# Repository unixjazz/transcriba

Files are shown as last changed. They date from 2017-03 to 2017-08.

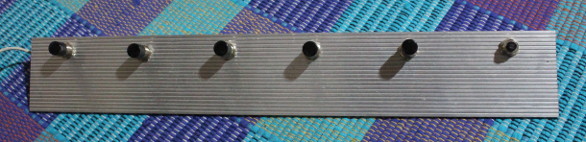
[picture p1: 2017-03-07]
img/pedal_0.1.jpg

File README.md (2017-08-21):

# Transcriba 0.3

Integrates VLC media player with an arduino-based USB pedal for audio
transcription.
 
This script is based on Jeffrey Ness' [raw keyboad access
code](https://github.com/jness).  It was inspired and re-written from
'vlccontrol' by [Derek
Barnett](https://wiki.videolan.org/How_to_use_VLC_for_transcription_in_linux).
It uses Al's [Pyperclip](https://pypi.python.org/pypi/pyperclip/1.5.1) for the
usage of the clipboard function on Mac, Windoze, and Linux.
 
Tested with the PRO MICRO Leonardo-compatible board. Here is the pinout: (it 
works with other Leonardo-compatible boards, Teensy, etc.)

```
Pin     Key Assignment            Function
------------------------------------------------
D02     KEY_LEFTCTRL + KEY_F7     Pause/Play 
D03     KEY_LEFTCTRL + KEY_F8     Get Timecode
D04     KEY_LEFTCTRL + KEY_F9     Jump Forward 
D05     KEY_LEFTCTRL + KEY_F10    Jump Backward
D06     KEY_LEFTCTRL + KEY_F11    Speed-Up  
D07     KEY_LEFTCTRL + KEY_F12    Slow-Down
```

## Getting Started

You need to configure VLC before using the script:

* Open VLC: preferences: advanced preferences and configure its interface to 
use 'RC', check the option 'fake tty' and 'UNIX socket command input' to 
the path of the script;
 
* Open 'keyboard.map' for a list of keycodes. Edit transcriba.py and change the
keycodes according to your environment;

* Plug your USB pedal and launch the script.

## Assembly Instructions

The prototype was based on a L-shaped aluminum bar (which can be found in any
hardware store), a collection of buttons, wires, and an ATmega32U4 MCU (which
can be found in many projects, most notably on the Arduino Leonardo):

[Pedal Transcriba prototype](pedal_0.1.jpg)

TODO: describe the assembly process w/ the PCB, as soon as it is ready!

## Licensing

Each dependency has specific licensing requirements. Check their respective
files for further information.  This script is distributed under the GPL
version 2. For further information, read 'LICENSE'.

*Enjoy Transcribing!*
 (just kidding...)

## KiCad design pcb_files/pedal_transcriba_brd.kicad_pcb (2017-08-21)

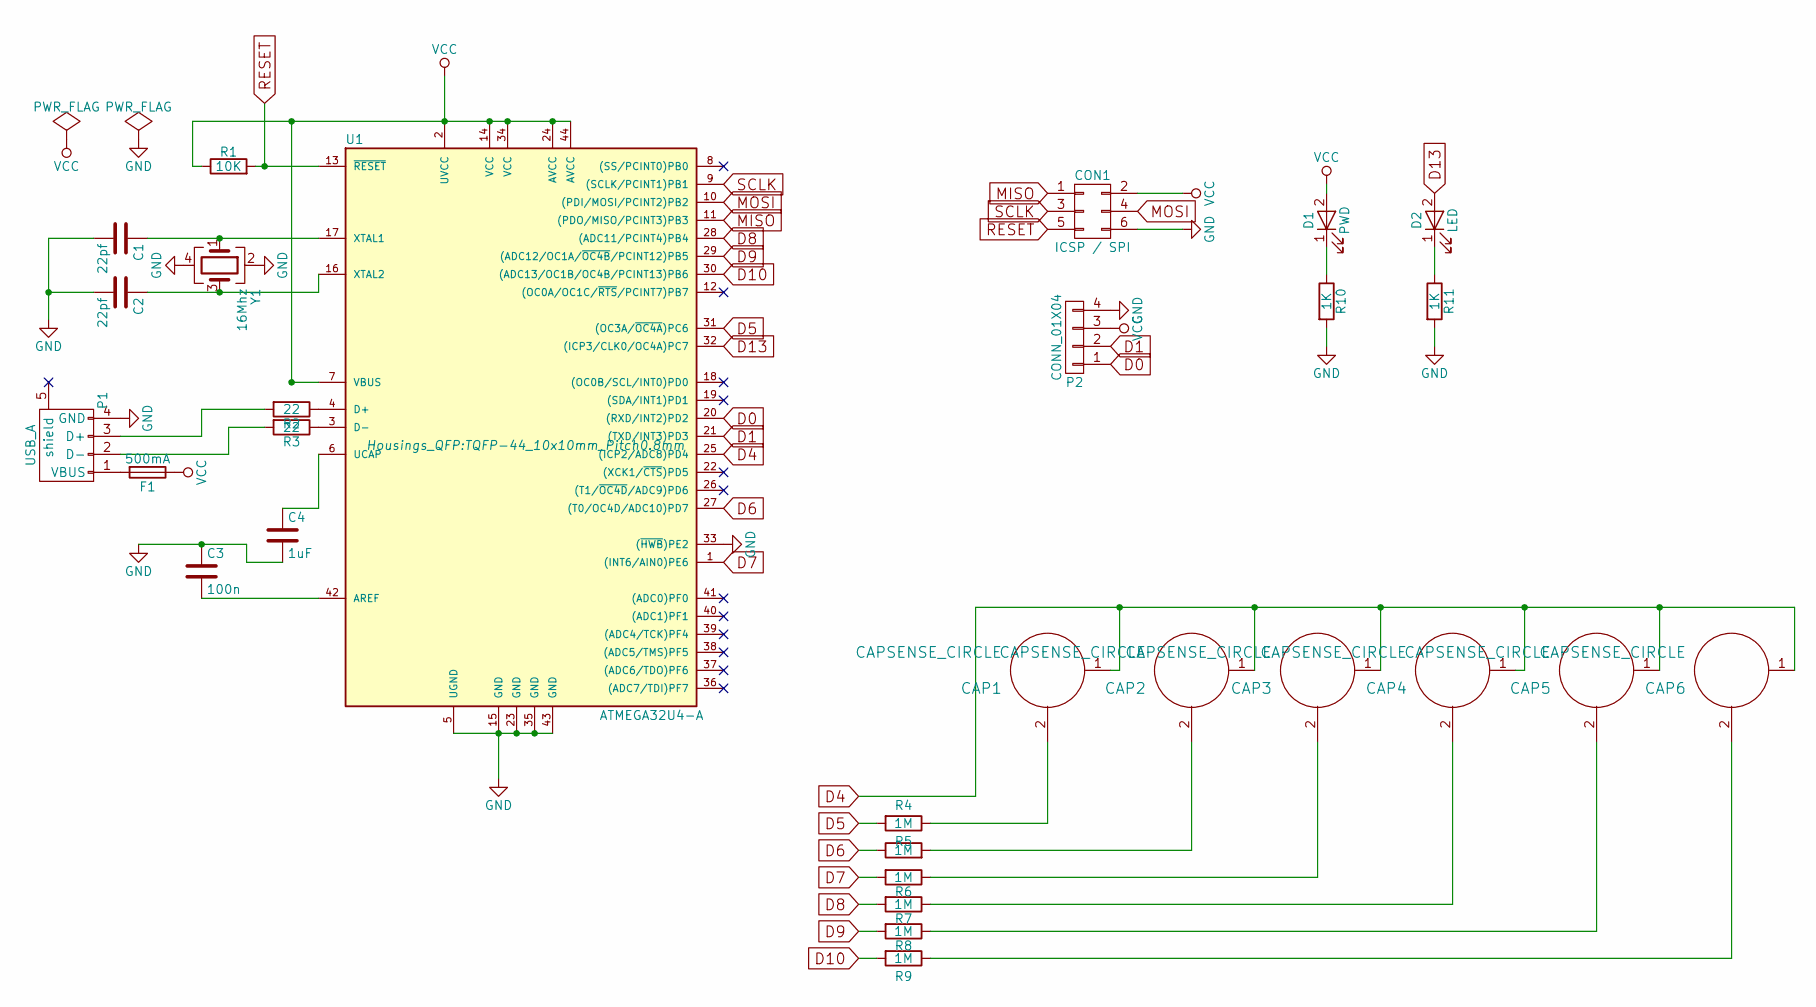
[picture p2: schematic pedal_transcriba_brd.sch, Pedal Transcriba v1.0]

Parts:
C1, C2: 22pf; C_0201
C3: 100n; C_0201
C4: 1uF; C_0201
CAP1, CAP2, CAP3, CAP4, CAP5, CAP6: CAPSENSE_CIRCLE; CAPSENSE-CIRCLE-D10MM-MOD
CON1: ICSP / SPI; Pin_Header_Straight_2x03
D1: PWD; LED_0603
D2: LED; LED_0603
F1: 500mA; Fuse_SMD1206_Reflow
P1: USB_A; USB_Micro-B_10103594-0001LF
P2: CONN_01X04; Pin_Header_Straight_1x04
R1: 10K; R_0201
R2, R3: 22; R_0201
R4, R5, R6, R7, R8, R9: 1M; R_0201
R10, R11: 1K; R_0201
U1: ATMEGA32U4-A; TQFP-44_10x10mm_Pitch0.8mm
Y1: 16Mhz; Crystal_SMD_Abracon_ABM3B-4pin_5.0x3.2mm

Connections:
D0: P2.1, U1.20 ((RXD/INT2)PD2)
D1: P2.2, U1.21 ((TXD/INT3)PD3)
D4: CAP1.1 (BUTTON), CAP2.1 (BUTTON), CAP3.1 (BUTTON), CAP4.1 (BUTTON), CAP5.1 (BUTTON), CAP6.1 (BUTTON), U1.25 ((ICP2/ADC8)PD4)
D5: R4.2, U1.31 ((OC3A/~OC4A~)PC6)
D6: R5.1, U1.27 ((T0/OC4D/ADC10)PD7)
D7: R6.2, U1.1 ((INT6/AIN0)PE6)
D8: R7.2, U1.28 ((ADC11/PCINT4)PB4)
D9: R8.2, U1.29 ((ADC12/OC1A/~OC4B~/PCINT12)PB5)
D10: R9.2, U1.30 ((ADC13/OC1B/OC4B/PCINT13)PB6)
D13: D2.2 (A), U1.32 ((ICP3/CLK0/OC4A)PC7)
GND: C1.2, C2.2, C3.1, C4.2, CON1.6, P1.4 (GND), P2.4, R10.2, R11.2, U1.5 (UGND), U1.15 (GND), U1.23 (GND), U1.33 ((~HWB~)PE2), U1.35 (GND), U1.43 (GND), Y1.2, Y1.4
MISO: CON1.1, U1.11 ((PDO/MISO/PCINT3)PB3)
MOSI: CON1.4, U1.10 ((PDI/MOSI/PCINT2)PB2)
unnamed: C1.1, U1.17 (XTAL1), Y1.1
unnamed: C2.1, U1.16 (XTAL2), Y1.3
unnamed: C3.2, U1.42 (AREF)
unnamed: C4.1, U1.6 (UCAP)
unnamed: CAP1.2, R4.1
unnamed: CAP2.2, R5.2
unnamed: CAP3.2, R6.1
unnamed: CAP4.2, R7.1
unnamed: CAP5.2, R8.1
unnamed: CAP6.2, R9.1
unnamed 23: D1.1 (K), R10.1; also elsewhere on the board
unnamed: D2.1 (K), R11.1
unnamed: F1.2, P1.1 (VBUS)
unnamed: P1.2 (D-), R3.2
unnamed: P1.3 (D+), R2.2
unnamed: R2.1, U1.4 (D+)
unnamed: R3.1, U1.3 (D-)
RESET: CON1.5, R1.2, U1.13 (~RESET~)
SCLK: CON1.3, U1.9 ((SCLK/PCINT1)PB1)
VCC: CON1.2, D1.2 (A), F1.1, P2.3, R1.1, U1.2 (UVCC), U1.7 (VBUS), U1.14 (VCC), U1.24 (AVCC), U1.34 (VCC), U1.44 (AVCC); also elsewhere on the board

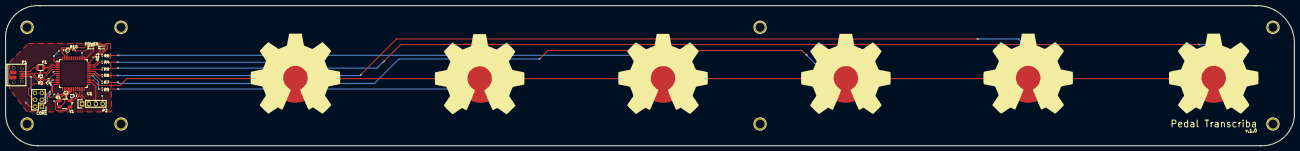
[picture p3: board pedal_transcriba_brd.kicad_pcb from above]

Board: 2 copper layers, 480.0 x 52.2 mm, 28 parts (0 on the bottom side), 31 nets.

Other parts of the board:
POWER: PWD; LED_0603

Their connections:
unnamed 23: POWER.1; also elsewhere on the board
VCC: POWER.2; also elsewhere on the board

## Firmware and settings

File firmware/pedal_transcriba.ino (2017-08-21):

/* 
 * Pedal Transcriba 0.1
 * --------------------------------------------------------------
 * Luis Felipe R. Murillo -- luisfelipe@ucla.edu 
 * This code is public domain
 * --------------------------------------------------------------
 * Modified for Sparkfun PRO Micro and Keates' code for joystick 
 * --------------------------------------------------------------
 */

#include "Keyboard.h"

// Pin definitions
const int BUT1_PIN = 2;
const int BUT2_PIN = 3;
const int BUT3_PIN = 4;
const int BUT4_PIN = 5;
const int BUT5_PIN = 6;
const int BUT6_PIN = 7;

// Previous states
boolean button1State = false;
boolean button2State = false;
boolean button3State = false;
boolean button4State = false;
boolean button5State = false;
boolean button6State = false;

void setup()
{
  // Pin definitions
  pinMode(BUT1_PIN, INPUT);
  pinMode(BUT2_PIN, INPUT);
  pinMode(BUT3_PIN, INPUT);
  pinMode(BUT4_PIN, INPUT);
  pinMode(BUT5_PIN, INPUT);
  pinMode(BUT6_PIN, INPUT);
  
  // Use pull-up resistors
  digitalWrite(BUT1_PIN, HIGH);
  digitalWrite(BUT2_PIN, HIGH);
  digitalWrite(BUT3_PIN, HIGH);
  digitalWrite(BUT4_PIN, HIGH);
  digitalWrite(BUT5_PIN, HIGH);
  digitalWrite(BUT6_PIN, HIGH);
  
  Keyboard.begin();
}

void loop()
{ 
  // Button 1 pressed
  if (!button1State && digitalRead(BUT1_PIN) == LOW)
  {
    button1State = true;
    Keyboard.press(KEY_LEFT_CTRL);
    Keyboard.press(KEY_F7);
    delay(200);
  }

  // Button 1 released
  if (button1State && digitalRead(BUT1_PIN) == HIGH)
  {
    button1State = false;
    Keyboard.releaseAll();
  }

  // Button 2 pressed
  if (!button2State && digitalRead(BUT2_PIN) == LOW)
  {
    button2State = true;
    Keyboard.press(KEY_LEFT_CTRL);
    Keyboard.press(KEY_F8);
    delay(200);
  }    

  // Button 2 released
  if (button2State && digitalRead(BUT2_PIN) == HIGH)
  {
    button2State = false;
    Keyboard.releaseAll();
  }

  // Button 3 pressed
  if (!button3State && digitalRead(BUT3_PIN) == LOW)
  {
    button3State = true;
    Keyboard.press(KEY_LEFT_CTRL);
    Keyboard.press(KEY_F9);
    delay(200);
  }

  // Button 3 released
  if (button3State && digitalRead(BUT3_PIN) == HIGH)
  {
    button3State = false;
    Keyboard.releaseAll();
  } 
 
  // Button 4 pressed
  if (!button4State && digitalRead(BUT4_PIN) == LOW)
  {
    button4State = true;
    Keyboard.press(KEY_LEFT_CTRL);
    Keyboard.press(KEY_F10);
    delay(200);
  }

  // Button 4 released
  if (button4State && digitalRead(BUT4_PIN) == HIGH)
  {
    button4State = false;
    Keyboard.releaseAll();
  }
 
  // Button 5 pressed
  if (!button5State && digitalRead(BUT5_PIN) == LOW)
  {
    button5State = true;
    Keyboard.press(KEY_LEFT_CTRL);
    Keyboard.press(KEY_F11);
    delay(200);
  }

  // Button 5 released
  if (button5State && digitalRead(BUT5_PIN) == HIGH)
  {
    button5State = false;
    Keyboard.releaseAll();
  }
  
  // Button 6 pressed
  if (!button5State && digitalRead(BUT6_PIN) == LOW)
  {
    button5State = true;
    Keyboard.press(KEY_LEFT_CTRL);
    Keyboard.press(KEY_F12);
    delay(200);
  }

  // Button 6 released
  if (button5State && digitalRead(BUT6_PIN) == HIGH)
  {
    button5State = false;
    Keyboard.releaseAll();
  }
}

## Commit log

2017-03-07 adding pedal prototype image
2017-08-21 added PyQt version of the script + KiCad design files.
    [pedal_transcriba_brd-B.Mask.gbs, pedal_transcriba_brd-B.SilkS.gbo, pedal_transcriba_brd-Bottom.gbl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]

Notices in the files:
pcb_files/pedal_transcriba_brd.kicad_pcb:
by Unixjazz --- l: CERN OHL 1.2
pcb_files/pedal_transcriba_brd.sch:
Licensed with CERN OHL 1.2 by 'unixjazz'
